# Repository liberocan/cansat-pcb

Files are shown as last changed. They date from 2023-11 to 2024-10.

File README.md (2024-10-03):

# cansat-circuits
Diagrams, circuits, schemas and gerber files of LiberoCAN free and open source CanSat

## Components
Check out our [docs](https://github.com/liberocan/cansat-docs/blob/main/CIRCUIT.md) for components.

## Pictures
### PCB
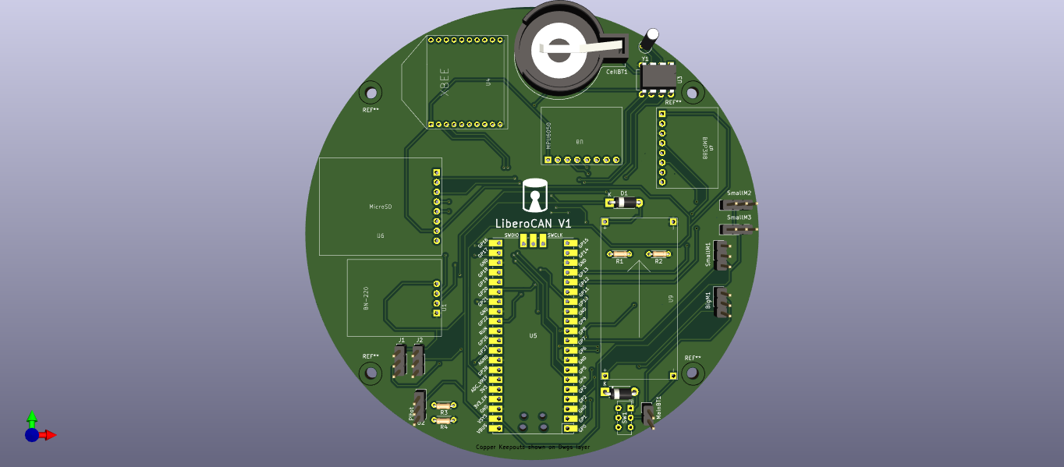
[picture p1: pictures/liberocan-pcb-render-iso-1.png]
Front

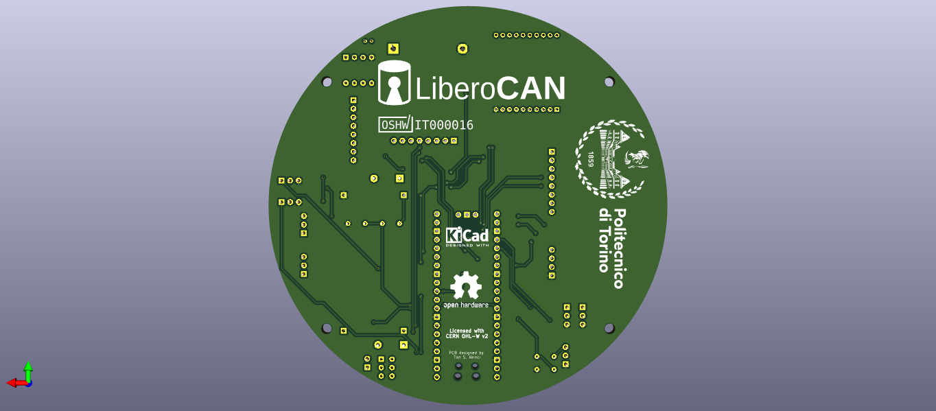
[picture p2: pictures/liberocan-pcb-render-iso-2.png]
Back


## TO-DO
- [X] Creation of part list
- [X] Ordering of parts
- [] Connecting and testing parts
- [x] Creation of schematics
- [x] Creation of PCB
- [x] Creation of gerber files for manufacturing
- [] Ordering and testing

## License
This free and open source hardware project is licensed with [CERN Open Hardware License Version 2 - Weakly Reciprocal](https://ohwr.org/project/cernohl/-/wikis/uploads/82b567f43ce515395f7ddbfbad7a8806/cern_ohl_w_v2.txt). The schematics are licensed with [Creative Commons Attribution-ShareAlike 4.0](https://creativecommons.org/licenses/by-sa/4.0/deed.en). The project has been certified by OSHW as Open Source Hardware (UID: [IT000016](https://certification.oshwa.org/it000016.html)).
</br>
<a href="https://certification.oshwa.org/it000016.html">
   
</a>

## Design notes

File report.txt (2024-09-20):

Warning: Width correction constrained.  The width correction value must be in the range of [0.000001 mm; 0.149999 mm] for the current design rules.
Plotted to '/home/tan/Documents/LAB-POLI/LAB-LIBEROCAN/cansat-pcb/pcb/gerber and drl/astrasat1-F_Cu.gbr'.
Plotted to '/home/tan/Documents/LAB-POLI/LAB-LIBEROCAN/cansat-pcb/pcb/gerber and drl/astrasat1-B_Cu.gbr'.
Plotted to '/home/tan/Documents/LAB-POLI/LAB-LIBEROCAN/cansat-pcb/pcb/gerber and drl/astrasat1-F_Paste.gbr'.
Plotted to '/home/tan/Documents/LAB-POLI/LAB-LIBEROCAN/cansat-pcb/pcb/gerber and drl/astrasat1-B_Paste.gbr'.
Plotted to '/home/tan/Documents/LAB-POLI/LAB-LIBEROCAN/cansat-pcb/pcb/gerber and drl/astrasat1-F_Silkscreen.gbr'.
Plotted to '/home/tan/Documents/LAB-POLI/LAB-LIBEROCAN/cansat-pcb/pcb/gerber and drl/astrasat1-B_Silkscreen.gbr'.
Plotted to '/home/tan/Documents/LAB-POLI/LAB-LIBEROCAN/cansat-pcb/pcb/gerber and drl/astrasat1-F_Mask.gbr'.
Plotted to '/home/tan/Documents/LAB-POLI/LAB-LIBEROCAN/cansat-pcb/pcb/gerber and drl/astrasat1-B_Mask.gbr'.
Plotted to '/home/tan/Documents/LAB-POLI/LAB-LIBEROCAN/cansat-pcb/pcb/gerber and drl/astrasat1-Edge_Cuts.gbr'.
Created Gerber job file '/home/tan/Documents/LAB-POLI/LAB-LIBEROCAN/cansat-pcb/pcb/gerber and drl/astrasat1-job.gbrjob'.
Plotted to '/home/tan/Documents/LAB-POLI/LAB-LIBEROCAN/cansat-pcb/pcb/gerber and drl/astrasat1-F_Cu.gbr'.
Plotted to '/home/tan/Documents/LAB-POLI/LAB-LIBEROCAN/cansat-pcb/pcb/gerber and drl/astrasat1-B_Cu.gbr'.
Plotted to '/home/tan/Documents/LAB-POLI/LAB-LIBEROCAN/cansat-pcb/pcb/gerber and drl/astrasat1-F_Paste.gbr'.
Plotted to '/home/tan/Documents/LAB-POLI/LAB-LIBEROCAN/cansat-pcb/pcb/gerber and drl/astrasat1-B_Paste.gbr'.
Plotted to '/home/tan/Documents/LAB-POLI/LAB-LIBEROCAN/cansat-pcb/pcb/gerber and drl/astrasat1-F_Silkscreen.gbr'.
Plotted to '/home/tan/Documents/LAB-POLI/LAB-LIBEROCAN/cansat-pcb/pcb/gerber and drl/astrasat1-B_Silkscreen.gbr'.
Plotted to '/home/tan/Documents/LAB-POLI/LAB-LIBEROCAN/cansat-pcb/pcb/gerber and drl/astrasat1-F_Mask.gbr'.
Plotted to '/home/tan/Documents/LAB-POLI/LAB-LIBEROCAN/cansat-pcb/pcb/gerber and drl/astrasat1-B_Mask.gbr'.
Plotted to '/home/tan/Documents/LAB-POLI/LAB-LIBEROCAN/cansat-pcb/pcb/gerber and drl/astrasat1-Edge_Cuts.gbr'.
Created Gerber job file '/home/tan/Documents/LAB-POLI/LAB-LIBEROCAN/cansat-pcb/pcb/gerber and drl/astrasat1-job.gbrjob'.
Info: Done.
Info: Done.

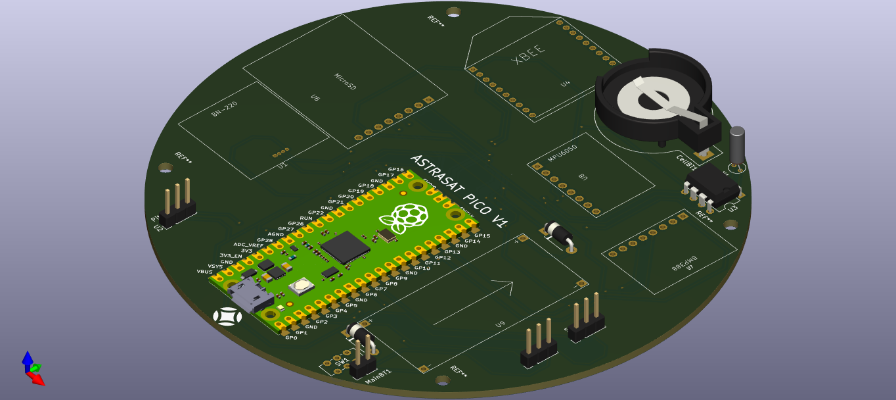
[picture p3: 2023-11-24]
pictures/astrasat-pcb-render-isometric-1.png

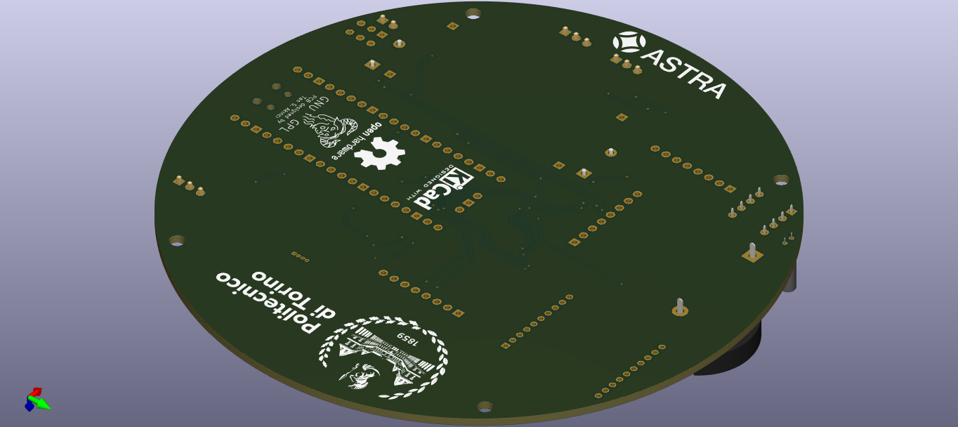
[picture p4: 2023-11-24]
pictures/astrasat-pcb-render-isometric-2.png

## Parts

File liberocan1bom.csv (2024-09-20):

Id | Designator | Footprint | Quantity | Designation | Supplier and ref
1 | J2 | PinHeader_1x03_P2.54mm_Vertical | 1 | CAM2
2 | U2 | PinHeader_1x03_P2.54mm_Vertical | 1 | ~
3 | U6 | Adafruit MicroSD Breakout | 1 | ~
4 | U1 | BN-220 | 1 | ~
5 | R3 | R_Axial_DIN0204_L3.6mm_D1.6mm_P5.08mm_Horizontal | 1 | 1K
6 | MainBT1 | PinHeader_1x02_P2.54mm_Vertical | 1 | Battery_Cell
7 | D2,D1 | D_DO-41_SOD81_P7.62mm_Horizontal | 2 | 1N5817
8 | SmallM3,BigM1,SmallM2,SmallM1 | PinHeader_1x03_P2.54mm_Vertical | 4 | Motor_Servo
9 | U9 | LM2596 Voltage Regulator board | 1 | ~
10 | J1 | PinHeader_1x03_P2.54mm_Vertical | 1 | CAM1
11 | U5 | RPi_Pico_SMD_TH | 1 | Pico
12 | CellBT1 | BatteryHolder_Keystone_103_1x20mm | 1 | Battery_Cell
13 | U3 | DIP-8_W7.62mm | 1 | DS1302+
14 | U4 | XBee S2C | 1 | ~
15 | Y1 | Crystal_C38-LF_D3.0mm_L8.0mm_Vertical | 1 | Crystal
16 | R2 | R_Axial_DIN0204_L3.6mm_D1.6mm_P5.08mm_Horizontal | 1 | 5K6
17 | R4 | R_Axial_DIN0204_L3.6mm_D1.6mm_P5.08mm_Horizontal | 1 | 2K
18 | SW1 | SW_E-Switch_EG1271_SPDT | 1 | SW_SPDT
19 | U7 | Adafruit BMP388 Blue | 1 | ~
20 | R1 | R_Axial_DIN0204_L3.6mm_D1.6mm_P5.08mm_Horizontal | 1 | 10K
21 | U8 | MPU6050 Module | 1 | ~

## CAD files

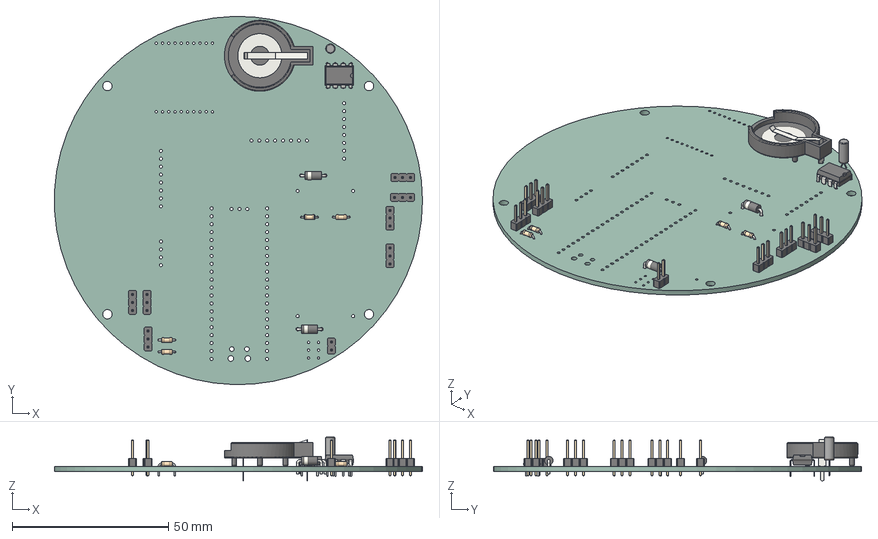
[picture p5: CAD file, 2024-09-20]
liberocan1.step
117.9 x 118.0 x 14.1 mm
PinHeader_1x03_P254mm_Vertical x 7
R_Axial_DIN0204_L36mm_D16mm_P508mm_Horizontal x 4
PinHeader_1x02_P254mm_Vertical
D_DO-41_SOD81_P7.62mm_Horizontal x 2
Keystone_103
DIP-8_W7.62mm
C38_LF_Vertical
liberocan1_PCB

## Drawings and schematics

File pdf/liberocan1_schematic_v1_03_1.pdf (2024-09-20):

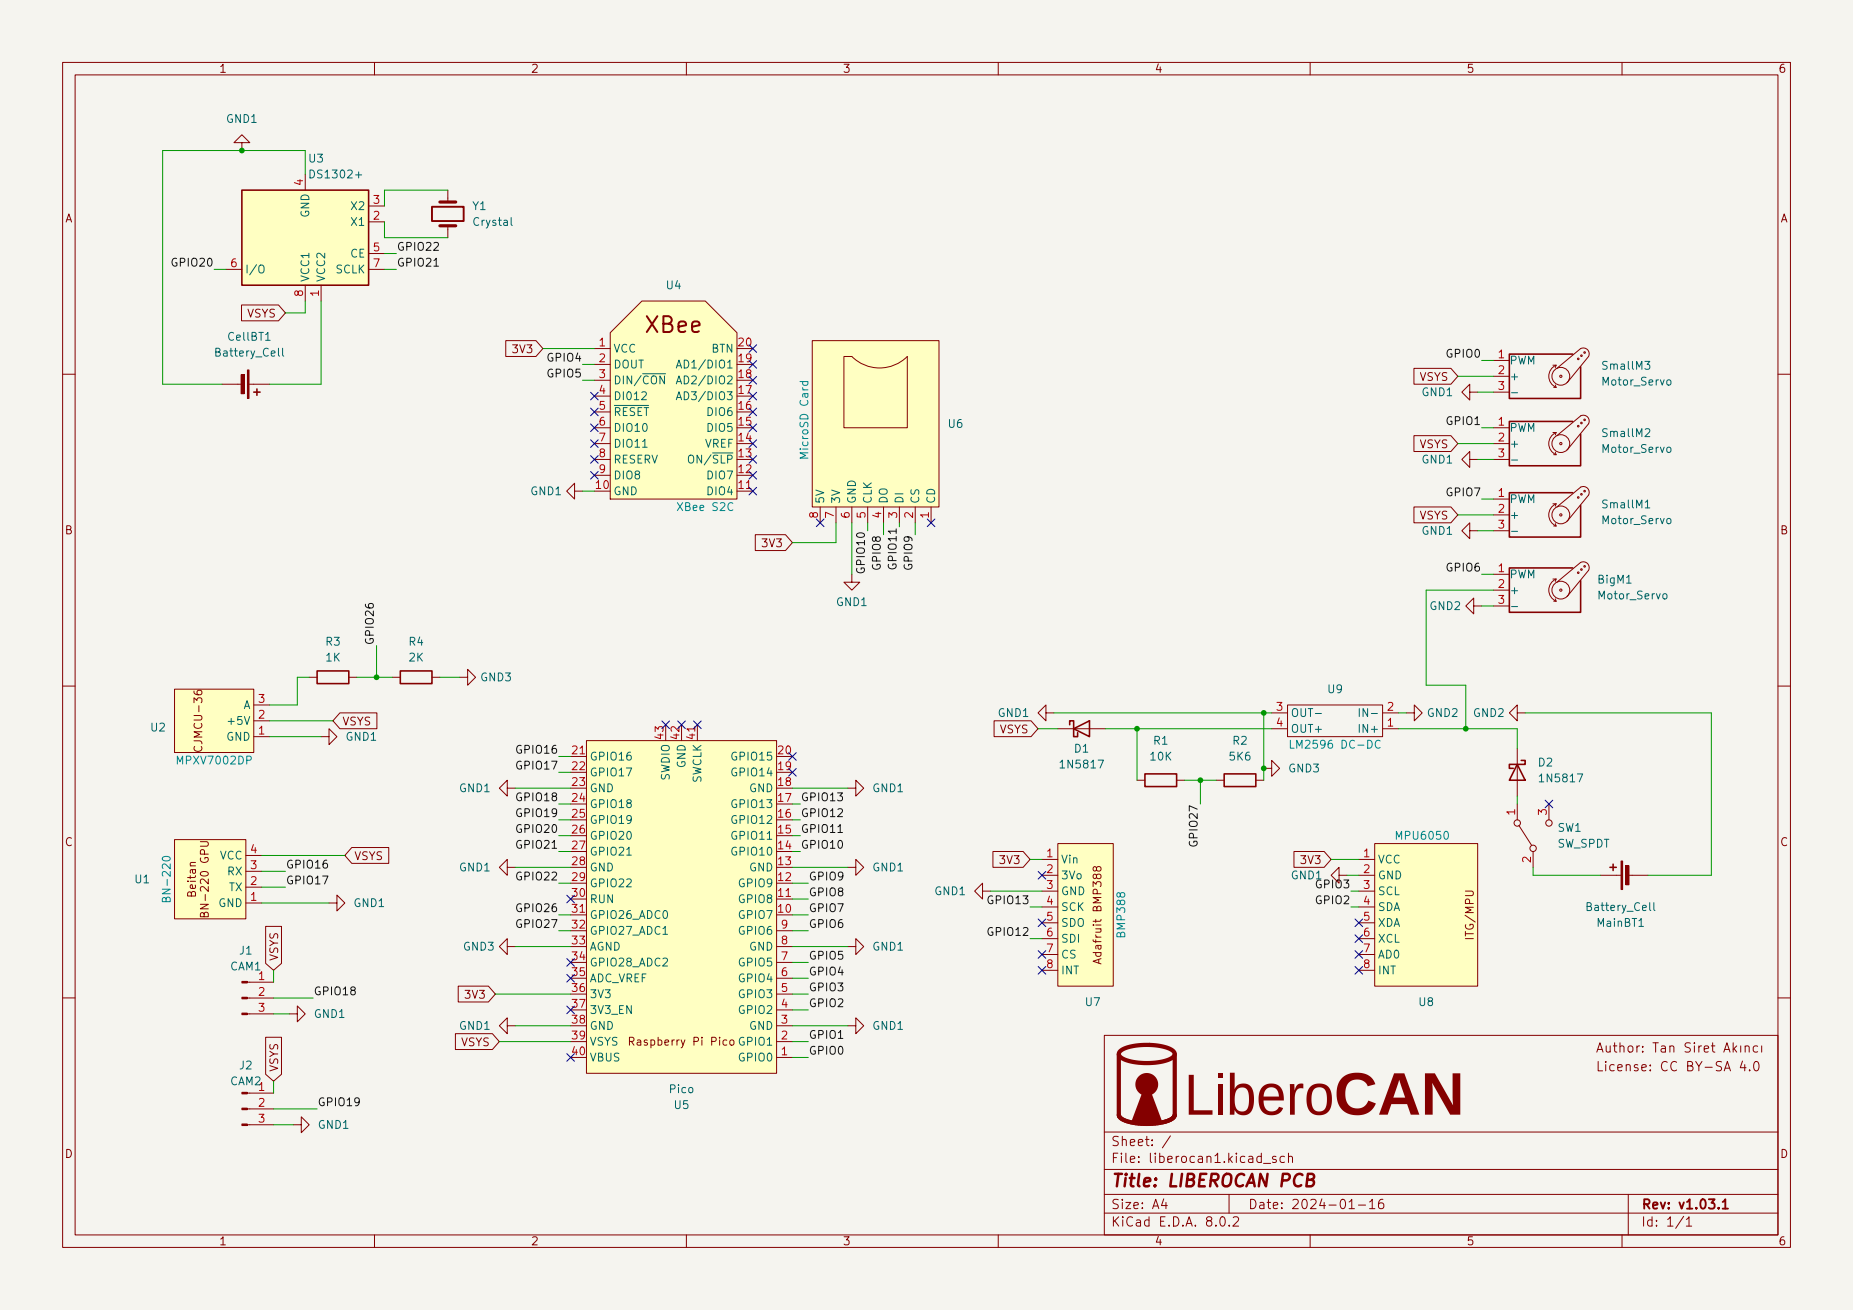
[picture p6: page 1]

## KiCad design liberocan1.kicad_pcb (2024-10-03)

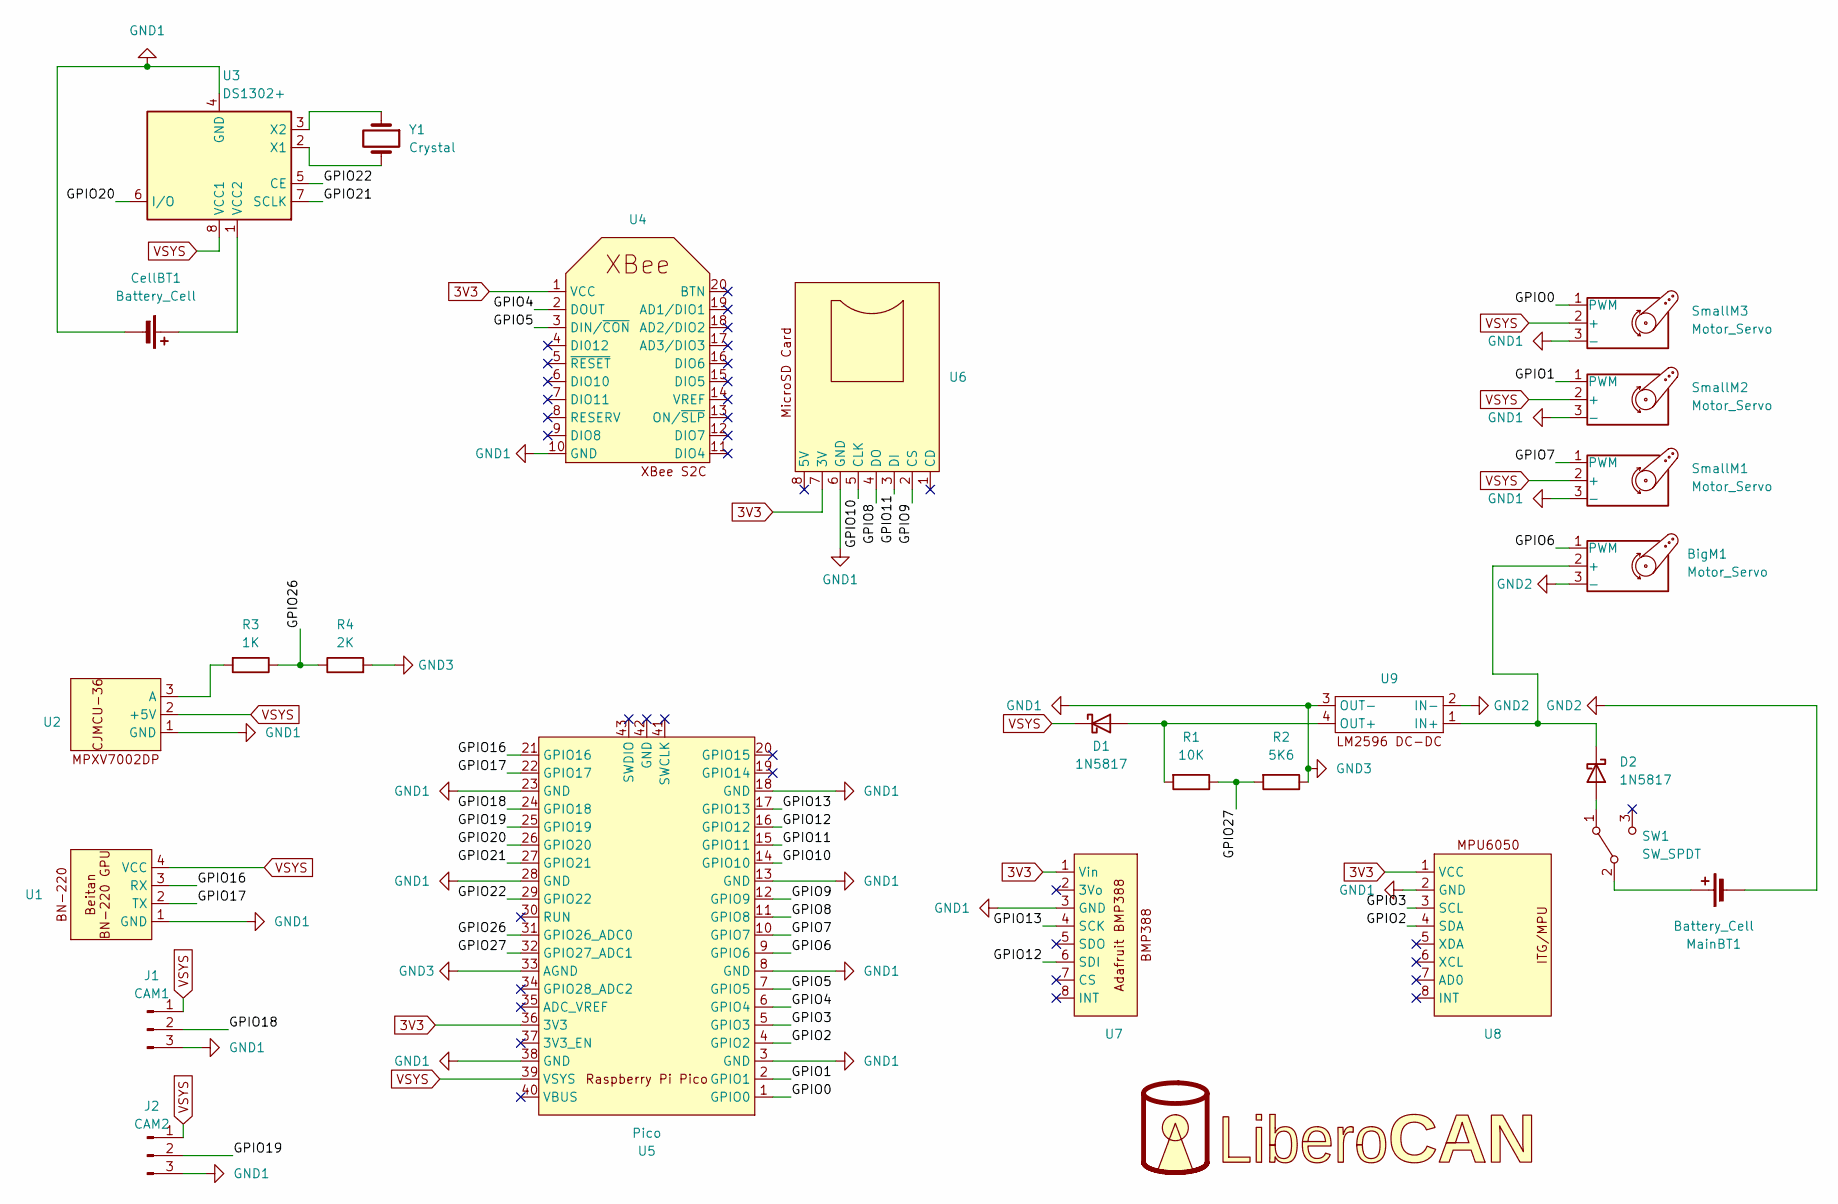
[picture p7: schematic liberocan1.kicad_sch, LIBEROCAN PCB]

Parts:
BigM1: Motor_Servo; PinHeader_1x03_P2.54mm_Vertical
CellBT1: Battery_Cell; BatteryHolder_Keystone_103_1x20mm
D1, D2: 1N5817; D_DO-41_SOD81_P7.62mm_Horizontal
J1: CAM1; PinHeader_1x03_P2.54mm_Vertical
J2: CAM2; PinHeader_1x03_P2.54mm_Vertical
MainBT1: Battery_Cell; PinHeader_1x02_P2.54mm_Vertical
R1: 10K; R_Axial_DIN0204_L3.6mm_D1.6mm_P5.08mm_Horizontal
R2: 5K6; R_Axial_DIN0204_L3.6mm_D1.6mm_P5.08mm_Horizontal
R3: 1K; R_Axial_DIN0204_L3.6mm_D1.6mm_P5.08mm_Horizontal
R4: 2K; R_Axial_DIN0204_L3.6mm_D1.6mm_P5.08mm_Horizontal
SW1: SW_SPDT; SW_E-Switch_EG1271_SPDT
SmallM1, SmallM2, SmallM3: Motor_Servo; PinHeader_1x03_P2.54mm_Vertical
U1: BN-220
U2: PinHeader_1x03_P2.54mm_Vertical
U3: DS1302+; DIP-8_W7.62mm
U4: XBee S2C
U5: Pico; RPi_Pico_SMD_TH
U6: Adafruit MicroSD Breakout
U7: Adafruit BMP388 Blue
U8: MPU6050 Module
U9: LM2596 Voltage Regulator board
U10: (no value)
Y1: Crystal; Crystal_C38-LF_D3.0mm_L8.0mm_Vertical

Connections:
3V3: U4.1 (VCC), U5.36 (3V3), U6.7 (3V), U7.1 (Vin), U8.1 (VCC)
/GPIO0: SmallM3.1 (PWM), U5.1 (GPIO0)
/GPIO1: SmallM2.1 (PWM), U5.2 (GPIO1)
/GPIO2: U5.4 (GPIO2), U8.4 (SDA)
/GPIO3: U5.5 (GPIO3), U8.3 (SCL)
/GPIO4: U4.2 (DOUT), U5.6 (GPIO4)
/GPIO5: U4.3 (DIN/~CON), U5.7 (GPIO5)
/GPIO6: BigM1.1 (PWM), U5.9 (GPIO6)
/GPIO7: SmallM1.1 (PWM), U5.10 (GPIO7)
/GPIO8: U5.11 (GPIO8), U6.4 (DO)
/GPIO9: U5.12 (GPIO9), U6.2 (CS)
/GPIO10: U5.14 (GPIO10), U6.5 (CLK)
/GPIO11: U5.15 (GPIO11), U6.3 (DI)
/GPIO12: U5.16 (GPIO12), U7.6 (SDI)
/GPIO13: U5.17 (GPIO13), U7.4 (SCK)
/GPIO16: U1.3 (RX), U5.21 (GPIO16)
/GPIO17: U1.2 (TX), U5.22 (GPIO17)
/GPIO18: J1.2, U5.24 (GPIO18)
/GPIO19: J2.2, U5.25 (GPIO19)
/GPIO20: U3.6 (I/O), U5.26 (GPIO20)
/GPIO21: U3.7 (SCLK), U5.27 (GPIO21)
/GPIO22: U3.5 (CE), U5.29 (GPIO22)
/GPIO26: R3.1, R4.1, U5.31 (GPIO26_ADC0)
/GPIO27: R1.1, R2.2, U5.32 (GPIO27_ADC1)
GND1: CellBT1.2 (-), J1.3, J2.3, R2.1, R4.2, SmallM1.3 (-), SmallM2.3 (-), SmallM3.3 (-), U1.1 (GND), U2.1 (GND), U3.4 (GND), U4.10 (GND), U5.3 (GND), U5.8 (GND), U5.13 (GND), U5.18 (GND), U5.23 (GND), U5.28 (GND), U5.33 (AGND), U5.38 (GND), U6.6 (GND), U7.3 (GND), U8.2 (GND), U9.3 (OUT-)
GND2: BigM1.3 (-), MainBT1.2 (-), U9.2 (IN-)
unnamed: BigM1.2 (+), D2.1 (K), U9.1 (IN+)
unnamed: CellBT1.1 (+), U3.1 (VCC2)
unnamed: D1.2 (A), R1.2, U9.4 (OUT+)
unnamed: D2.2 (A), SW1.1 (A)
unnamed: MainBT1.1 (+), SW1.2 (B)
unnamed: R3.2, U2.3 (A)
unnamed: U3.2 (X1), Y1.2
unnamed: U3.3 (X2), Y1.1
VSYS: D1.1 (K), J1.1, J2.1, SmallM1.2 (+), SmallM2.2 (+), SmallM3.2 (+), U1.4 (VCC), U2.2 (+5V), U3.8 (VCC1), U5.39 (VSYS)

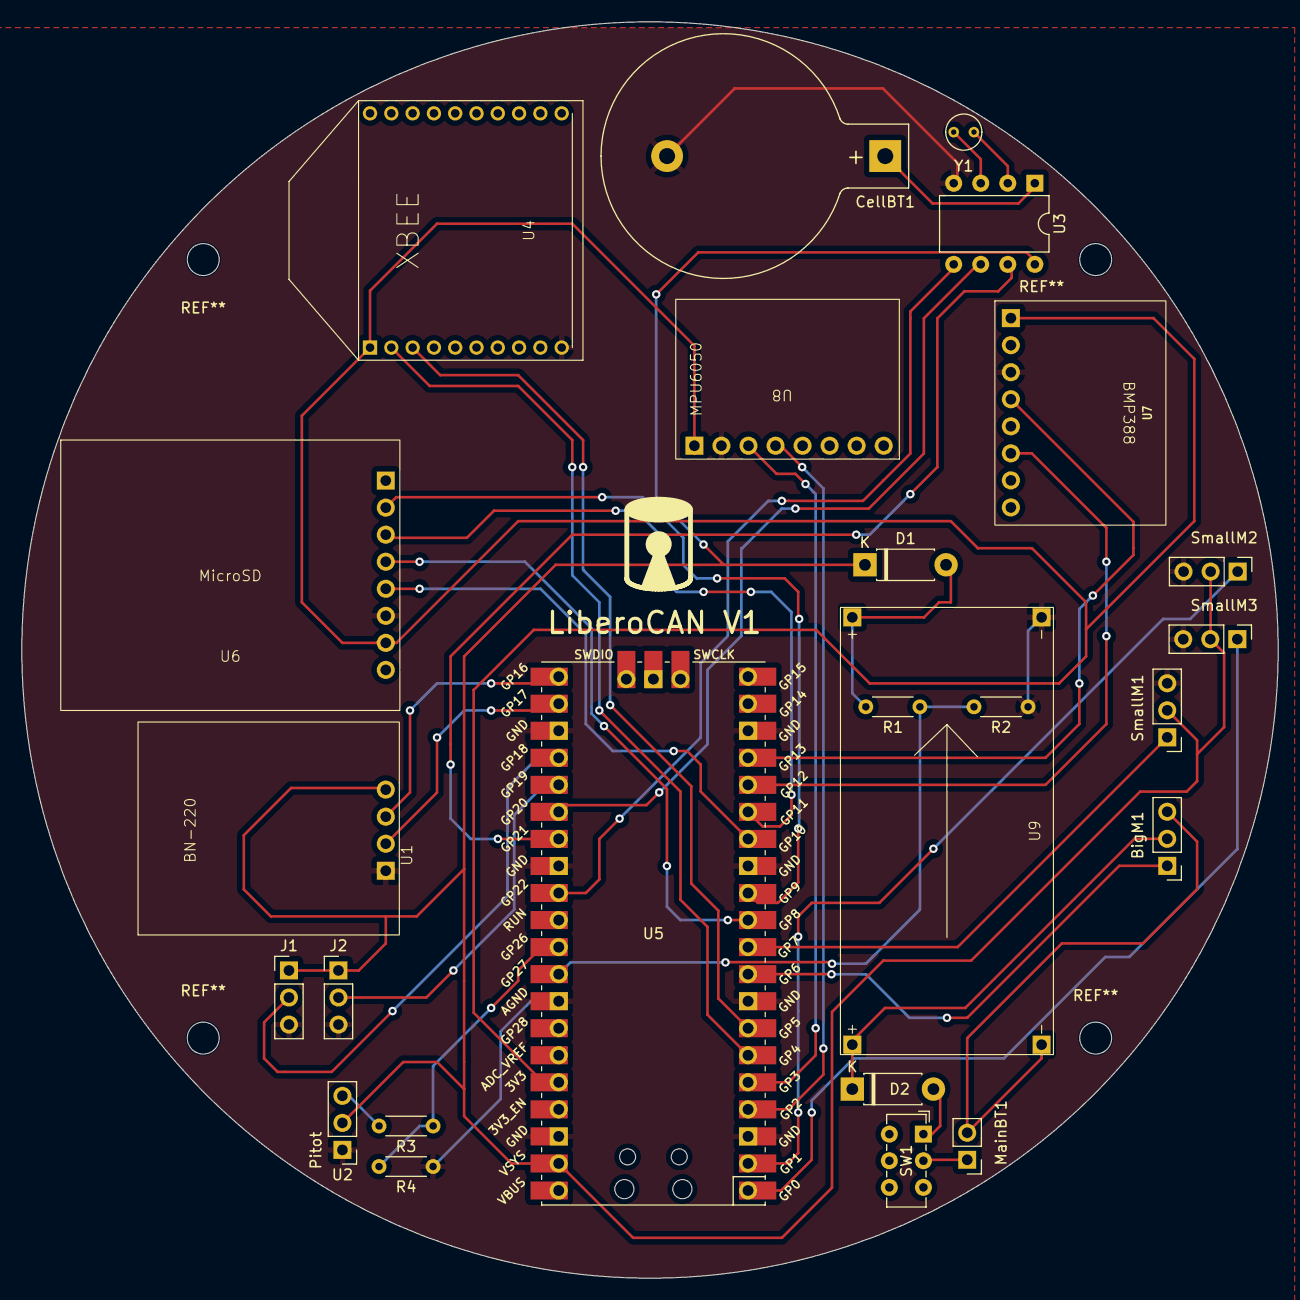
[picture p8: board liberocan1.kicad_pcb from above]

Board: 2 copper layers, 118.0 x 118.0 mm, 25 parts (0 on the bottom side), 35 nets.

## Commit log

2023-11-18 first version of schematic
    [astrasat1.kicad_pcb, astrasat1.kicad_sch]
2023-11-18 export last minor revision
    [astrasat1.kicad_sch]
2023-11-18 save and export minor revision
    [astrasat1.kicad_sch]
2023-11-18 fix minor issue
    [astrasat1.kicad_sch]
2023-11-21 add new schematic and some custom footprints
    [astrasat1.kicad_sch]
2023-11-22 edit schematic, complete all footprints and annotate them with the symbols
    [astrasat1.csv, astrasat1.kicad_sch]
2023-11-23 add pcb and 3d files
    [astrasat1.csv, astrasat1.kicad_pcb, astrasat1.kicad_sch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]
2023-11-23 edit pcb and generate gerber files
    [astrasat1-B_Cu.gbr, astrasat1-B_Mask.gbr, astrasat1-B_Paste.gbr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]
2023-11-23 solve issues and edit readme
    [astrasat1-B_Cu.gbr, astrasat1-B_Mask.gbr, astrasat1-B_Paste.gbr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]
2023-11-24 reduce pcb size
    [astrasat1-B_Cu.gbr, astrasat1-B_Mask.gbr, astrasat1-B_Paste.gbr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]
2023-12-15 Update PCB
    [astrasat1.csv, astrasat1.kicad_pcb, astrasat1.kicad_sch]
2024-10-03 add OSHW cert
    [liberocan1-B_Cu.gbr, liberocan1-B_Mask.gbr, liberocan1-B_Paste.gbr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]
2024-10-03 add OSHW on pcb
    [liberocan1.kicad_pcb]

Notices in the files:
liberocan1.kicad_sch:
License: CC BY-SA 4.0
